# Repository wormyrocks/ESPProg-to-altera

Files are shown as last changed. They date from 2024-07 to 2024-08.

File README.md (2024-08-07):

# ESP-Prog to Altera adapter

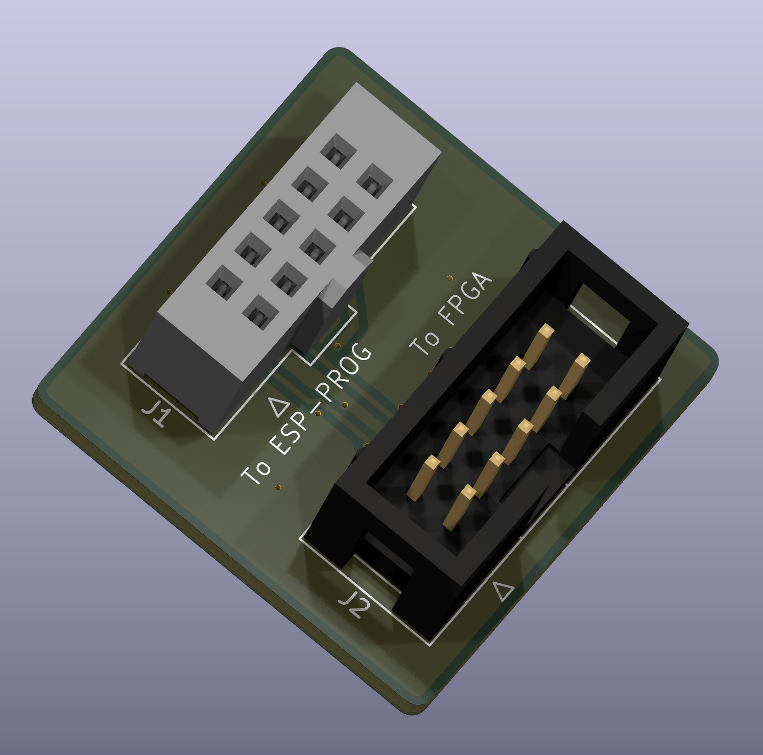
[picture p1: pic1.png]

Lets you use a $10 [ESP-Prog](https://docs.espressif.com/projects/esp-iot-solution/en/latest/hw-reference/ESP-Prog_guide.html) programmer as the equivalent of an Altera USB Blaster.  

The FT2232HL on the ESP-Prog supports JTAG/MPSSE, which means you can use it to flash an FPGA using [openFPGALoader](https://trabucayre.github.io/openFPGALoader/compatibility/cable.html).  

This board can be ordered assembled from JLCPCB using the gerbers and BOM included in the release/ directory. Or you can hand solder it, obviously.  

# Update

It works. Tested with [Waveshare CoreEP4CE6](https://www.waveshare.com/wiki/CoreEP4CE6).

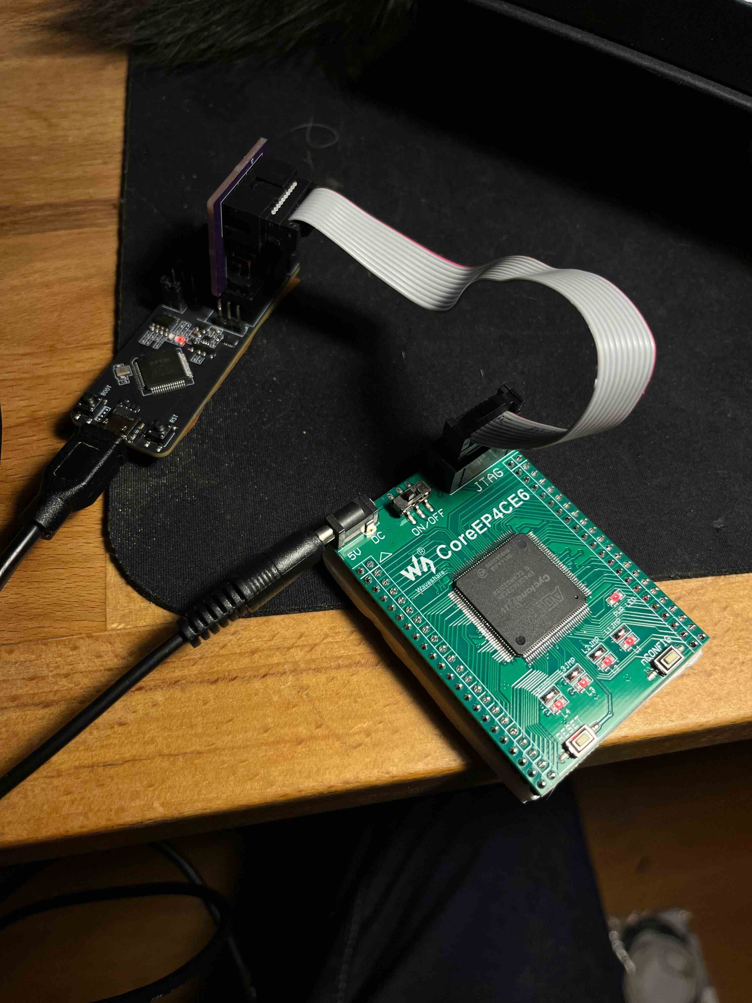
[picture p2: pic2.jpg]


`openFPGALoader -c ft2232 --fpga-part ep4ce622 -f [binary].rbf`

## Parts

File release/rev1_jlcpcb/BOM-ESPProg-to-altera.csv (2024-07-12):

Comment | Designator | Footprint | LCSC
SFH11-PBPC-D05-ST-BK | J1 | IDC-Header_2x05_P2.54mm_Vertical | C358739
X9555WV-2X05-6TV01 | J2 | IDC-Header_2x05_P2.54mm_Vertical | C5665

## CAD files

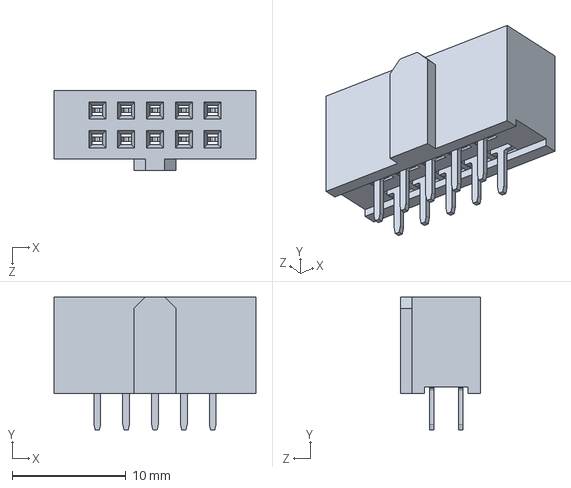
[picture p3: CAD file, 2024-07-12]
SFH11-_ _ _C-D05-ST-_ _.STEP
17.8 x 11.7 x 7.00 mm

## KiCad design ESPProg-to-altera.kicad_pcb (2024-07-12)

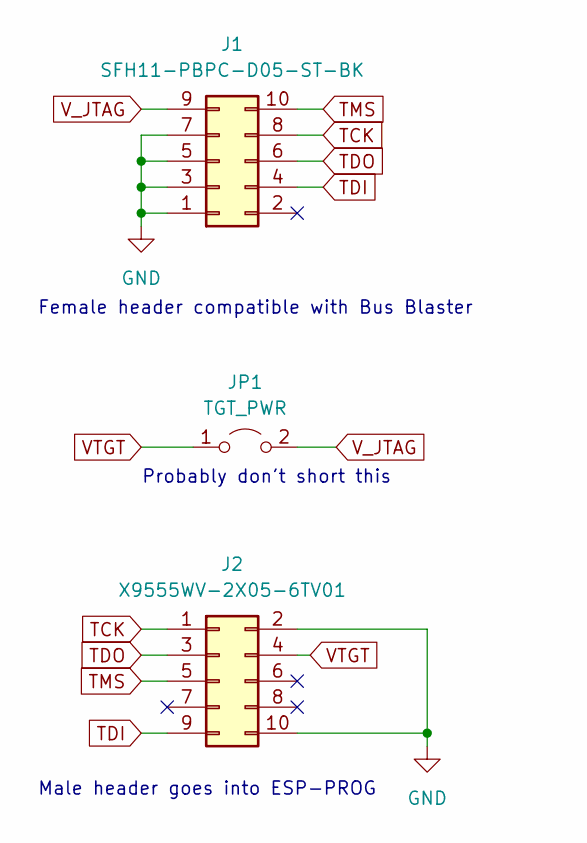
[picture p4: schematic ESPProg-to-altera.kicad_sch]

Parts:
J1: SFH11-PBPC-D05-ST-BK; IDC-Header_2x05_P2.54mm_Vertical; LCSC C3322462
J2: X9555WV-2X05-6TV01; IDC-Header_2x05_P2.54mm_Vertical; LCSC C706914
JP1: TGT_PWR; SolderJumper-2_P1.3mm_Open_TrianglePad1.0x1.5mm

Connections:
GND: J1.1, J1.3, J1.5, J1.7, J2.2, J2.10
TCK: J1.8, J2.1
TDI: J1.4, J2.9
TDO: J1.6, J2.3
TMS: J1.10, J2.5
VTGT: J2.4, JP1.1 (A)
V_JTAG: J1.9, JP1.2 (B)

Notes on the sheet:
Male header goes into ESP-PROG
Probably don't short this
Female header compatible with Bus Blaster

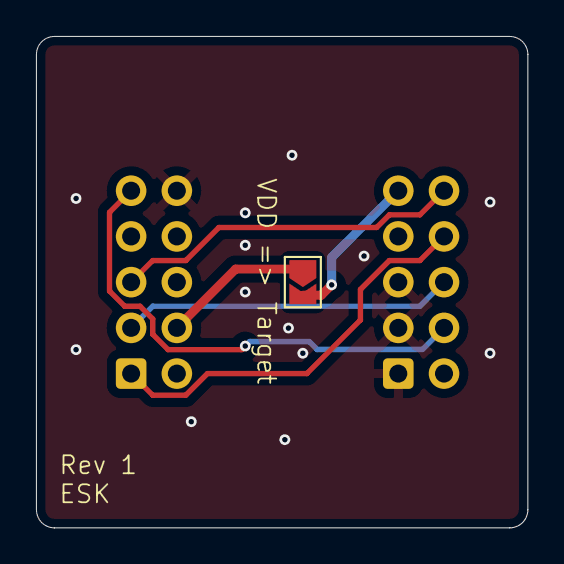
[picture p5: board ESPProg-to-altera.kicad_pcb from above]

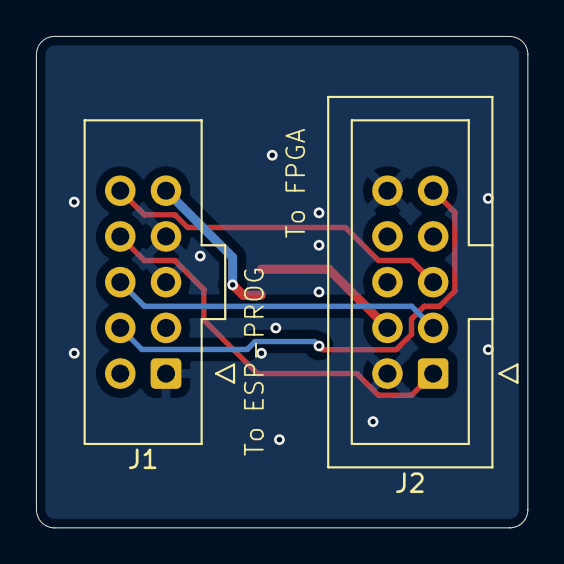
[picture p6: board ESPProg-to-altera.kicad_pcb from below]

Board: 2 copper layers, 27.3 x 27.3 mm, 3 parts (2 on the bottom side), 7 nets.
